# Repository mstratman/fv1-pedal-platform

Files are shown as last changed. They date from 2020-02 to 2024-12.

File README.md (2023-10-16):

# Mimir's Well

This repository contains everything you need to build the [Mimir's Well](https://mas-effects.com/mimirs-well/) guitar pedal. You can build it from a [kit or PCB](https://shop.mas-effects.com/collections/diy/mimirs-well).

Directories:

* `arduino`: code for the display driver, and for writing the "yellow" EEPROMs
* `assembly`: documents to help people building from a [kit or PCB](https://shop.mas-effects.com/collections/diy/mimirs-well)
* `eeprom-helper`: simple tool to help when creating EEPROMs. see its README 
* `pcb`: gerber and dxf files, e.g. if you want to produce your own PCB
* `schematics`: schematics
* `v1`: a one-off prototype (which is now my most-used pedal)

## Writing EEPROMs

The pedal has 2 pairs of 24LC32A EEPROMs. Each pair contains a bank of 8 programs, and has a "Yellow" EEPROM and a "Blue" EEPROM.  The colors aren't significant, and just refer to the color I use when writing each chip's number on it. It's a simple way to avoid getting them mixed up.

There are lots of ways to write to EEPROMs, and this is only one of them.

### Yellow

This holds the program name and control labels for each program in the bank. I use this [EEPROM Helper](https://github.com/mstratman/fv1-pedal-platform/tree/master/eeprom-helper) script to make the label text file, or the arduino file.

#### Using an EEPROM programmer:

You can write to it using these shell scripts: [burn-labels.sh and make-labels.sh](https://gist.github.com/mstratman/d541932adb592097963afa8c9aeca4c1).

####  Using an arduino:

You can also write it using an [Arduino sketch](/arduino/eeprom/eeprom.ino). You can hook it up as follows:

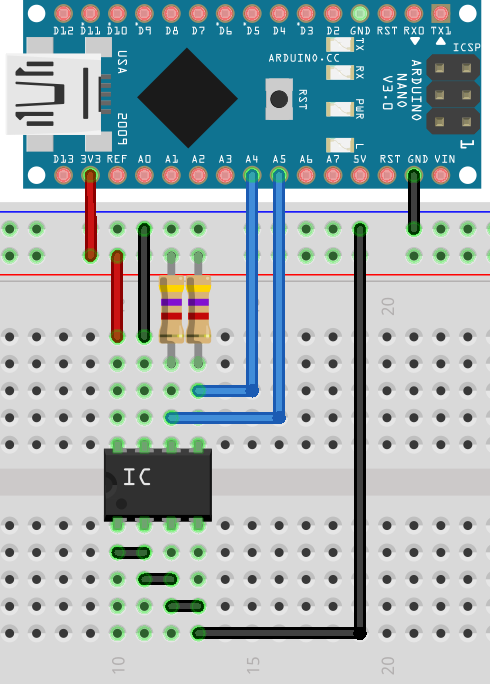
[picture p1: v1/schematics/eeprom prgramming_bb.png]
connecting EEPROM to Arduino for writing


### Blue

This holds the FV-1 programs.

You may be be able to write the banks using an arduino and a custom sketch, but I simply use a very inexpensive EEPROM programmer.  Specifically I use a USB CH341 EEPROM programmer.  These can be found for about $5.  You may need to find and install USB drivers. 

I use the [ch341eeprom](https://github.com/command-tab/ch341eeprom) commandline tool on Mac OS X to write the data to the USB programmer.  If you're not on Mac you'll need to find an alternative tool.

To create these banks I do the following:

1. Create a "hex" bank using [SpinAsm assembler](http://spinsemi.com/products.html)
    1. Unfortunately this only runs on Windows. [An alternate assembler](https://github.com/ndf-zz/asfv1) exists but I haven't tried it.
2. Convert it to a "bin" file using the `srec_cat` util from the "srecord" package
    1. `brew install srecord` on Mac
    2. `srec_cat bank-input.hex -Intel -o bank-output.bin -binary`
3. Erase the EEPROM, probably optional
    1. `ch341eeprom -v -s 24c32 -e`
4. Write the bin file
    1. `ch341eeprom -v -s 24c32 -w bank-output.bin`
5. Check for problems. Optional but recommended
    1. `ch341eeprom -v -s 24c32 -r /tmp/eeprom.bin # read back the data`
    2. `diff /tmp/eeprom.bin bank-output.bin # this should not output anything`

[Here is a script I use for steps 2-5](https://gist.github.com/mstratman/5ede44bfd3bc87219b2a90b9920d51e1).

## "EEPROM Helper" tool

To help streamline this process I have a really simple tool I use: [eeprom helper](https://github.com/mstratman/fv1-pedal-platform/tree/master/eeprom-helper)

It's just a simple javascript page that lets me check which programs I'll be burning, then it does 2 things:

1. Gives a snippet of arduino code or a text list of labels for the burning the Yellow chip, described above.
2. Lists the spn files for reference, which is helpful when manually working with SpinAsm Assembler in step 1 while burning the Blue chip.

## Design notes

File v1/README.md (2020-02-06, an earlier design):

# FV-1 Pedal Platform

## Overview

This project contains the files for a guitar effects pedal utilizing a TFT screen, Atmega display driver, FV-1 DSP module, and EEPROMs to hold the FV-1 programs and labels.

The schematics and PCBs included reflect the v1 prototype, which was pieced together utilizing an [Arachnid board from Pedalpcb](https://www.pedalpcb.com/product/arachnid/), and 4 etched PCBs for additional functionality.  Future builds will be simplified to use a single, manufactured board.

## DSP code to run on the pedal

**[https://mstratman.github.io/fv1-programs/](https://mstratman.github.io/fv1-programs/)**

## PCBs

* [Arachnid board from Pedalpcb](https://www.pedalpcb.com/product/arachnid/) is very similar to the "typical application" circuit from the FV-1 datasheet
* 5V voltage regulator board: This is not included in the `pcbs` directory of this project. It's simply a small piece of veroboard with the circuit shown in the [pedal schematic](schematics/pedal.png).
* TFT board
* Arduino and EEPROM board
* Rotary switch board

## Arduino or Atmega328p

This was originally built using an Atmega328p rather than full nano board, but the, and you could just as easily use that. I recommend setting it up with a 16MHz crystal to maximize display refresh rate.

I switched to an Arduino Nano board because it was quicker and easier to test and debug since it has a built-in USB controller, and I found a pack of clone boards for a few dollars. Now that the code is stable, this isn't nearly as important, so an Atmega328p would be fine.

## Rotary switch

We're reading the rotary switch from both the FV-1 and the Atmega. We really only need one set of diodes to do this, but wiring into the FV-1's Arachnid board is more trouble than it's worth, so we just have a duplicate set of them for the Atmega to use.

When v2 is built onto a single board, we will eliminate the duplication.

## EEPROM

We have two EEPROM's.  One for the FV-1 with the DSP code, and one for the Atmega with the names of the programs and the labels.  We could just hard-code the program names and control labels into the Atmega, but this allows us to swap out programs more easily without needing to reprogram it.

For ease of programming, and because we control the data going onto it, we're simply going to store each string on one of the 32byte pages. This allows us to ignore page boundaries, and simply read and write one page at a time.

Note: Running the EEPROM off 3.3V did not work with my Arduino board.  It works fine with 5V though.

## Bank switching

...

## Fonts

The `.h` files for the fonts are created using [fontconvert](https://github.com/adafruit/Adafruit-GFX-Library/tree/master/fontconvert) from the [Adafruit GFX library](https://github.com/adafruit/Adafruit-GFX-Library).

## What's next (v2)

If I build a v2 using a fabricated board, I'll simplify it to a single set of switching diodes.

Second, I'll let it switch between two pairs of eeproms for 16 instead of 8 custom programs.

Possibly: I'll use the arduino to control program selection and have it skip over the built-in FV-1 programs that aren't very useful for guitar

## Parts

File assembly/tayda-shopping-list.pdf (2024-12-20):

### Parts - grouped

Designa tor | Qty | Name | Tayda Part # | Link | NOTE
C4,C11 | 2 | 10u | A-1067 | https://www.taydaelectronics.com/10uf-35v-105c-jrb-radial-electrolytic-capacitor-5x11mm.html (https://www.taydaelectronics.com/10uf-35v-105c-jrb-radial-electrolytic-capacitor-5x11mm.html)
C6,C10 | 2 | 100u | A-972 | https://www.taydaelectronics.com/100uf-16v-105c-jrb-radial-electrolytic-capacitor-5x11mm.html (https://www.taydaelectronics.com/100uf-16v-105c-jrb-radial-electrolytic-capacitor-5x11mm.html)
C7,C8 | 2 | 47u | A-6062 | https://www.taydaelectronics.com/47uf-25v-105c-jrb-radial-electrolytic-capacitor-5x11mm.html (https://www.taydaelectronics.com/47uf-25v-105c-jrb-radial-electrolytic-capacitor-5x11mm.html)
C1,C9 | 2 | 100n | A-6984 | https://www.taydaelectronics.com/0-1uf-100v-5-polyester-film-box-type-capacitor-jfj.html (https://www.taydaelectronics.com/0-1uf-100v-5-polyester-film-box-type-capacitor-jfj.html)
C2,C12, C13,C15 ,C16,C1 9 | 6 | 1u MLCC | A-5706 | https://www.taydaelectronics.com/1-uf-50v-multilayer-monolithic-ceramic-capacitor-x7r-jym-5705.html (https://www.taydaelectronics.com/1-uf-50v-multilayer-monolithic-ceramic-capacitor-x7r-jym-5705.html)
C3 | 1 | 1n | A-557 | https://www.taydaelectronics.com/1nf-0-001uf-100v-5-polyester-film-box-type-capacitor.html (https://www.taydaelectronics.com/1nf-0-001uf-100v-5-polyester-film-box-type-capacitor.html)
C5 | 1 | 15p | A-1393 | https://www.taydaelectronics.com/15pf-50v-multilayer-monolithic-ceramic-capacitor.html (https://www.taydaelectronics.com/15pf-50v-multilayer-monolithic-ceramic-capacitor.html)
C14 | 1 | 2n2 | A-4413 | https://www.taydaelectronics.com/2-2nf-0-0022uf-100v-5-polyester-film-box-type-capacitor-jfj.html (https://www.taydaelectronics.com/2-2nf-0-0022uf-100v-5-polyester-film-box-type-capacitor-jfj.html)
C17 | 1 | 220p | A-7056 | https://www.taydaelectronics.com/220-pf-50v-multilayer-monolithic-ceramic-capacitor-c0g.html (https://www.taydaelectronics.com/220-pf-50v-multilayer-monolithic-ceramic-capacitor-c0g.html)
C18 | 1 | 470p | A-5704 | https://www.taydaelectronics.com/470pf-50v-multilayer-monolithic-ceramic-capacitor-x7r-jym.html (https://www.taydaelectronics.com/470pf-50v-multilayer-monolithic-ceramic-capacitor-x7r-jym.html)
R1,R3 | 2 | 1M | A-2277 | https://www.taydaelectronics.com/resistors/1-4w-metal-film-resistors/10-x-resistor-1m-ohm-1-4w-1-metal-film-pkg-of-10.html (https://www.taydaelectronics.com/resistors/1-4w-metal-film-resistors/10-x-resistor-1m-ohm-1-4w-1-metal-film-pkg-of-10.html)
R2,R4,R 25,R29,R 27,R26,R 24,R23,R 22,R21 | 10 | 1k | A-2200 | https://www.taydaelectronics.com/resistors/1-4w-metal-film-resistors/10-x-resistor-1k-ohm-1-4w-1-metal-film-pkg-of-10.html (https://www.taydaelectronics.com/resistors/1-4w-metal-film-resistors/10-x-resistor-1k-ohm-1-4w-1-metal-film-pkg-of-10.html)
R5,R6,R 7,R8,R9, R39 | 6 | 10k | A-2203 | https://www.taydaelectronics.com/resistors/1-4w-metal-film-resistors/10-x-resistor-10k-ohm-1-4w-1-metal-film-pkg-of-10.html (https://www.taydaelectronics.com/resistors/1-4w-metal-film-resistors/10-x-resistor-10k-ohm-1-4w-1-metal-film-pkg-of-10.html)
R28,R37 | 2 | 100 | A-2245 | https://www.taydaelectronics.com/resistors/1-4w-metal-film-resistors/resistor-100-ohm-1-4w-1-metal-film-pkg-of-10.html (https://www.taydaelectronics.com/resistors/1-4w-metal-film-resistors/resistor-100-ohm-1-4w-1-metal-film-pkg-of-10.html)
R30,R38, R10,R11, R12 | 5 | 100k | A-2248 | https://www.taydaelectronics.com/resistors/1-4w-metal-film-resistors/10-x-resistor-100k-ohm-1-4w-1-metal-film-pkg-of-10.html (https://www.taydaelectronics.com/resistors/1-4w-metal-film-resistors/10-x-resistor-100k-ohm-1-4w-1-metal-film-pkg-of-10.html)
R31,R32, R33,R34, R35,R36 | 6 | 15k | A-2182 | https://www.taydaelectronics.com/resistors/1-4w-metal-film-resistors/10-x-resistor-15k-ohm-1-4w-1-metal-film-pkg-of-10.html (https://www.taydaelectronics.com/resistors/1-4w-metal-film-resistors/10-x-resistor-15k-ohm-1-4w-1-metal-film-pkg-of-10.html)
R20 | 1 | 220 | A-2246 | https://www.taydaelectronics.com/resistors/1-4w-metal-film-resistors/resistor-220-ohm-1-4w-1-metal-film-pkg-of-10.html (https://www.taydaelectronics.com/resistors/1-4w-metal-film-resistors/resistor-220-ohm-1-4w-1-metal-film-pkg-of-10.html)
R19,R18, R17,R16 | 4 | 2k | A-2307 | https://www.taydaelectronics.com/resistors/1-4w-metal-film-resistors/resistor-2k-ohm-1-4w-1-metal-film-pkg-of-10.html (https://www.taydaelectronics.com/resistors/1-4w-metal-film-resistors/resistor-2k-ohm-1-4w-1-metal-film-pkg-of-10.html)
R13,R14, R15 | 3 | 4.7k | A-2310 | https://www.taydaelectronics.com/resistors/1-4w-metal-film-resistors/10-x-resistor-4-7k-ohm-1-4w-1-metal-film-pkg-of-10.html (https://www.taydaelectronics.com/resistors/1-4w-metal-film-resistors/10-x-resistor-4-7k-ohm-1-4w-1-metal-film-pkg-of-10.html)
POT1,P OT2,POT 3,VOLU ME | 4 | B100K | A-2963 | https://www.taydaelectronics.com/b100k-ohm-linear-taper-potentiometer-round-shaft-pc-mount-l.html (https://www.taydaelectronics.com/b100k-ohm-linear-taper-potentiometer-round-shaft-pc-mount-l.html)
MIX | 1 | B10K | A-2969 | https://www.taydaelectronics.com/b10k-ohm-linear-taper-potentiometer-round-shaft-pc-mount-l.html (https://www.taydaelectronics.com/b10k-ohm-linear-taper-potentiometer-round-shaft-pc-mount-l.html)
Q1 | 1 | 2N3904 | A-111 | https://www.taydaelectronics.com/2n3904-npn-general-propose-transistor.html (https://www.taydaelectronics.com/2n3904-npn-general-propose-transistor.html)

1

Q2 | 1 | BS170 | A-096 | https://www.taydaelectronics.com/bs170-mosfet-n-channel-60v-0-5a.html
DT-38 | 1 | 32.768 3x8MM | A-1592 | https://www.taydaelectronics.com/32-768-khz-crystal-cylender-3-x-8-mm.html (https://www.taydaelectronics.com/32-768-khz-crystal-cylender-3-x-8-mm.html) | INCLUDED IN KIT
D10,D2, D3,D4,D 6,D5,D7, D8,D9 | 9 | 1N4148 | A-157 | https://www.taydaelectronics.com/1n4148-switching-signal-diode.html
D1 | 1 | 1N5817 | A-159 | https://www.taydaelectronics.com/1n5817-diode-schottky-1a-20v.html
SW1 | 1 | SP8T rotary switch | | | INCLUDED IN KIT
SW2 | 1 | 3PDT On-Off-On | A-5488 | https://www.taydaelectronics.com/mini-toggle-switch-1m-series-3pdt-on-off-on.html (https://www.taydaelectronics.com/mini-toggle-switch-1m-series-3pdt-on-off-on.html)
U1 | 1 | FV-1 | | | INCLUDED IN KIT
U2 | 1 | TL074 | A-1138 | https://www.taydaelectronics.com/tl074-quad-operational-amplifier-j-fet-pdip-14-tl074cn.html (https://www.taydaelectronics.com/tl074-quad-operational-amplifier-j-fet-pdip-14-tl074cn.html)
U5 | 1 | L78L33 | A-492 | https://www.taydaelectronics.com/l78l33acz-78l33-3-3v-voltage-regulator-ic.html (https://www.taydaelectronics.com/l78l33acz-78l33-3-3v-voltage-regulator-ic.html)
U7 | 1 | 7805 | A-179 | https://www.taydaelectronics.com/lm7805-l7805-7805-voltage-regulator-ic-5v-1-5a.html (https://www.taydaelectronics.com/lm7805-l7805-7805-voltage-regulator-ic-5v-1-5a.html)
U3, U4, U9, U11 | 4 | 24LC32 A (MUST BE PROGR AMME D) | | | INCLUDED IN KIT
U8 (silkscree n shows U6) | 1 | ILI9341-2.8 TFT (SPI) | | | INCLUDED IN KIT
U10 | 1 | Arduino Nano (MUST BE PROGR AMME D) | | | INCLUDED IN KIT

(plus all off-board hardware )

2

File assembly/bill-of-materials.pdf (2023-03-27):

### Parts - grouped

Designator | Qty | Name
C4,C11 | 2 | 10u
C6,C10 | 2 | 100u
C7,C8 | 2 | 47u
C1,C9 | 2 | 100n
C2,C12,C13,C15,C16,C19 | 6 | 1u MLCC
C3 | 1 | 1n
C5 | 1 | 15p
C14 | 1 | 2n2
C17 | 1 | 220p
C18 | 1 | 470p
R1,R3 | 2 | 1M
R2,R4,R25,R29,R27,R26,R24,R23,R22,R21 | 10 | 1k
R5,R6,R7,R8,R9,R39 | 6 | 10k
R28,R37 | 2 | 100
R30,R38,R10,R11,R12 | 5 | 100k
R31,R32,R33,R34,R35,R36 | 6 | 15k
R20 | 1 | 220
R19,R18,R17,R16 | 4 | 2k
R13,R14,R15 | 3 | 4.7k
POT1,POT2,POT3,VOLUME | 4 | B100K | R20 | 220
MIX | 1 | B10K | R21 | 1k
Q1 | 1 | 2N3904 | R22 | 1k
Q2 | 1 | BS170 | R23 | 1k
DT-38 | 1 | 32.768 3x8MM | R24 | 1k
D10,D2,D3,D4,D6,D5,D7,D8,D9 | 9 | 1N4148 | R25 | 1k
D1 | 1 | 1N5817 | R26 | 1k
SW1 | 1 | SP8T rotary switch | R27 | 1k
SW2 | 1 | 3PDT On-Off-On | R28 | 100
U1 | 1 | FV-1 | R29 | 1k
U2 | 1 | TL074 | R30 | 100k
U5 | 1 | L78L33 | R31 | 15k
U7 | 1 | 7805 | R32 | 15k
U3, U4, U9, U11 | 4 | 24LC32A (MUST BE PROGRAMMED) | R33 | 15k
| | | R34 | 15k
| | | R35 | 15k
| | | R36 | 15k
| | | R37 | 100
| | | R38 | 100k
| | | R39 | 10k
U8 (silkscreen shows U6) | 1 | ILI9341-2.8 TFT (SPI)
U10 | 1 | Arduino Nano (MUST BE PROGRAMMED)

(plus all off-board hardware)

### Caps - ordered

Designator | Name | code
C1 | 100n | 104
C2 | 1u MLCC
C3 | 1n | 102
C4 | 10u
C5 | 15p | 150
C6 | 100u
C7 | 47u
C8 | 47u
C9 | 100n | 104
C10 | 100u
C11 | 10u
C12 | 1u MLCC
C13 | 1u MLCC
C14 | 2n2 | 222
C15 | 1u MLCC
C16 | 1u MLCC
C17 | 220p | 221
C18 | 470p | 471
C19 | 1u MLCC

### Resistors - ordered

Designator | Name
R1 | 1M
R2 | 1k
R3 | 1M
R4 | 1k
R5 | 10k
R6 | 10k
R7 | 10k
R8 | 10k
R9 | 10k
R10 | 100k
R11 | 100k
R12 | 100k
R13 | 4.7k
R14 | 4.7k
R15 | 4.7k
R16 | 2k
R17 | 2k
R18 | 2k
R19 | 2k

1

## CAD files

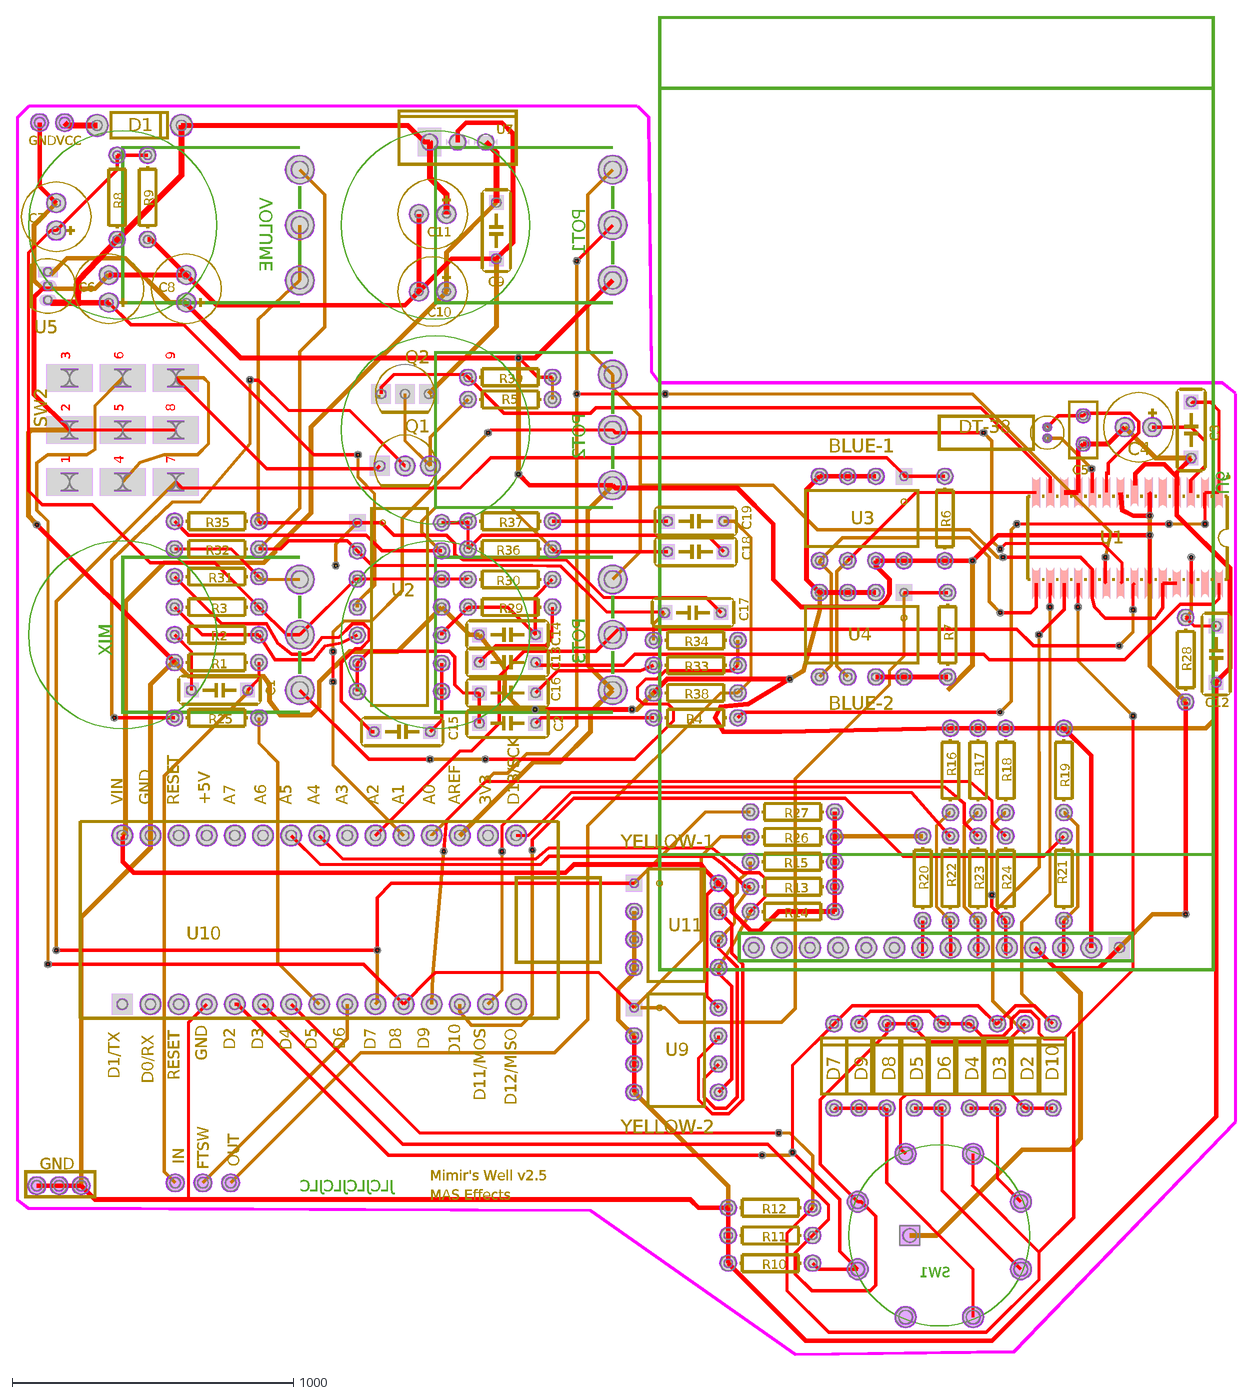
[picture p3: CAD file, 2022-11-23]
pcb/mimirs-well-2.5.dxf
JLCJLCJLCJLC
SW1
FTSW
GND
OUT
IN
VCC
Mimir's Well v2.5
MAS Effects
YELLOW-1
YELLOW-2
BLUE-1
BLUE-2
U6
POT1
POT2
POT3
VOLUME
MIX
C4
C6
C7
C8
C10
C11
D1
U11
U9
U10
D1/TX
+5V
D12/MISO
VIN
D13/SCK
D0/RX
RESET
D2
D3
D4
D5
D6
D7
D8
D9
D10
D11/MOSI
3V3
AREF
A0
A1
A2
A3
A4
A5
A6
A7
R27
R26
R24
R23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

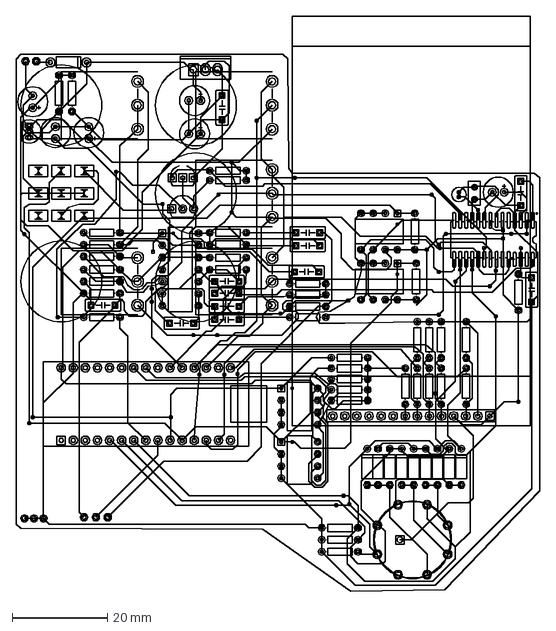
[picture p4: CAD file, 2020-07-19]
pcb/mimirs-well-2.4.dxf
110.0 x 120.7 mm

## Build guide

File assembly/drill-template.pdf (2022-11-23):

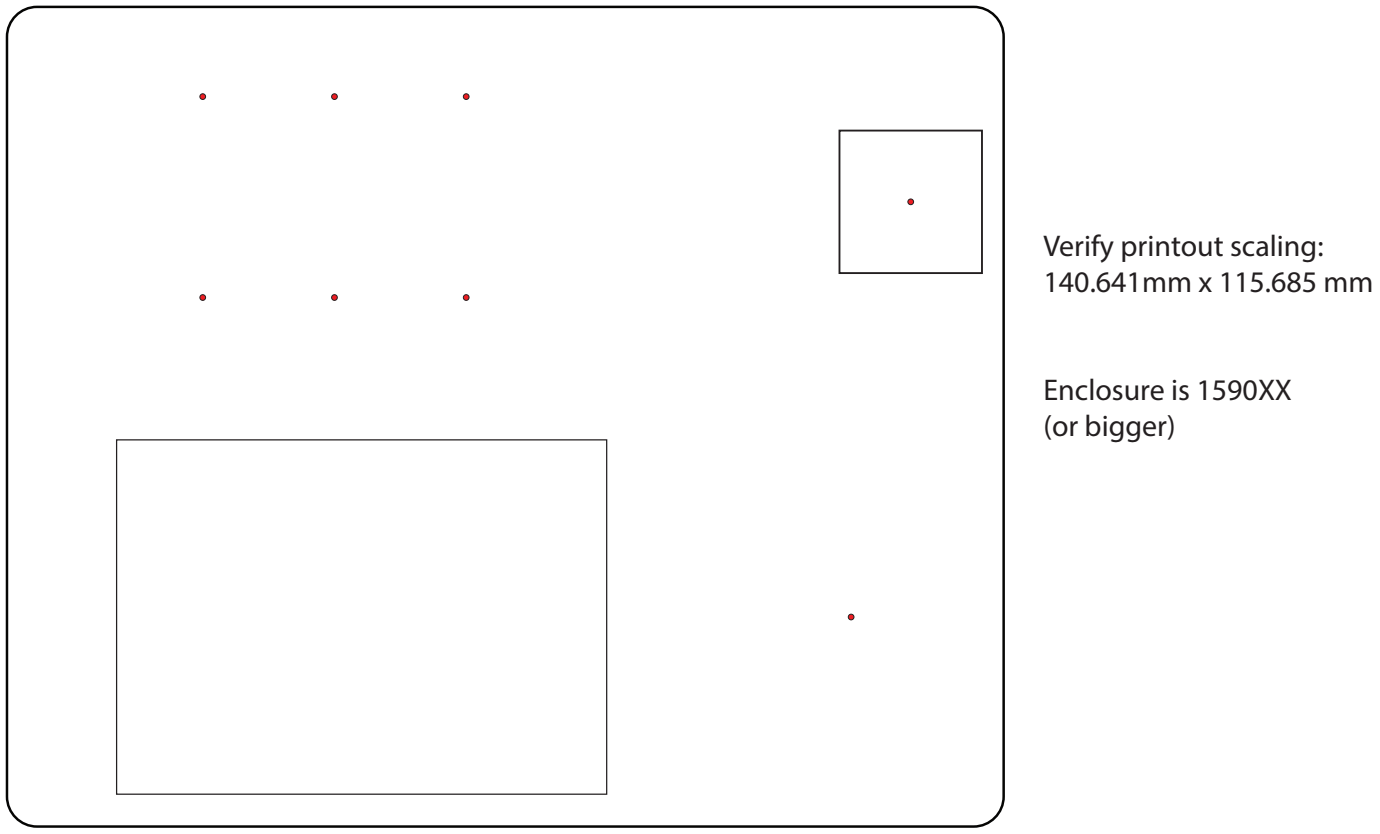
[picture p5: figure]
Verify printout scaling: 140.641mm x 115.685 mm; Enclosure is 1590XX (or bigger)
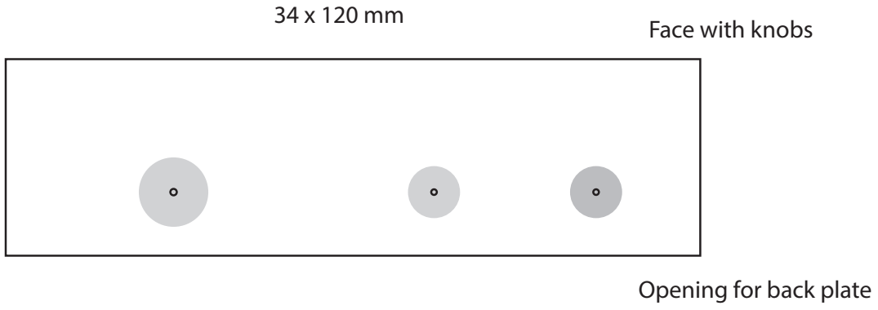
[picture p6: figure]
Opening for back plate; Face with knobs

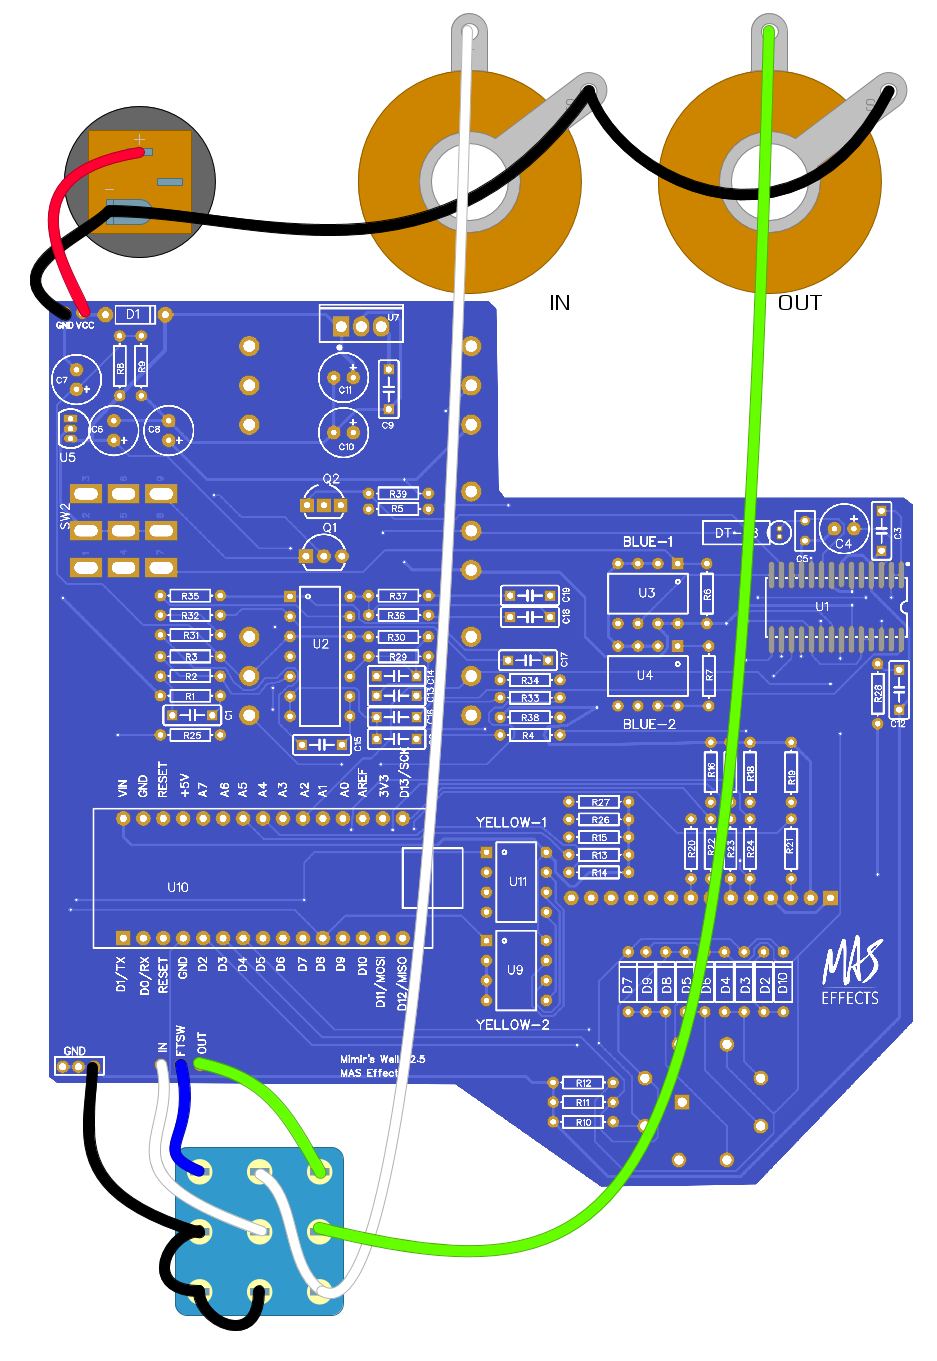
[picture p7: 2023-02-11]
assembly/mimirs-well-wiring.png

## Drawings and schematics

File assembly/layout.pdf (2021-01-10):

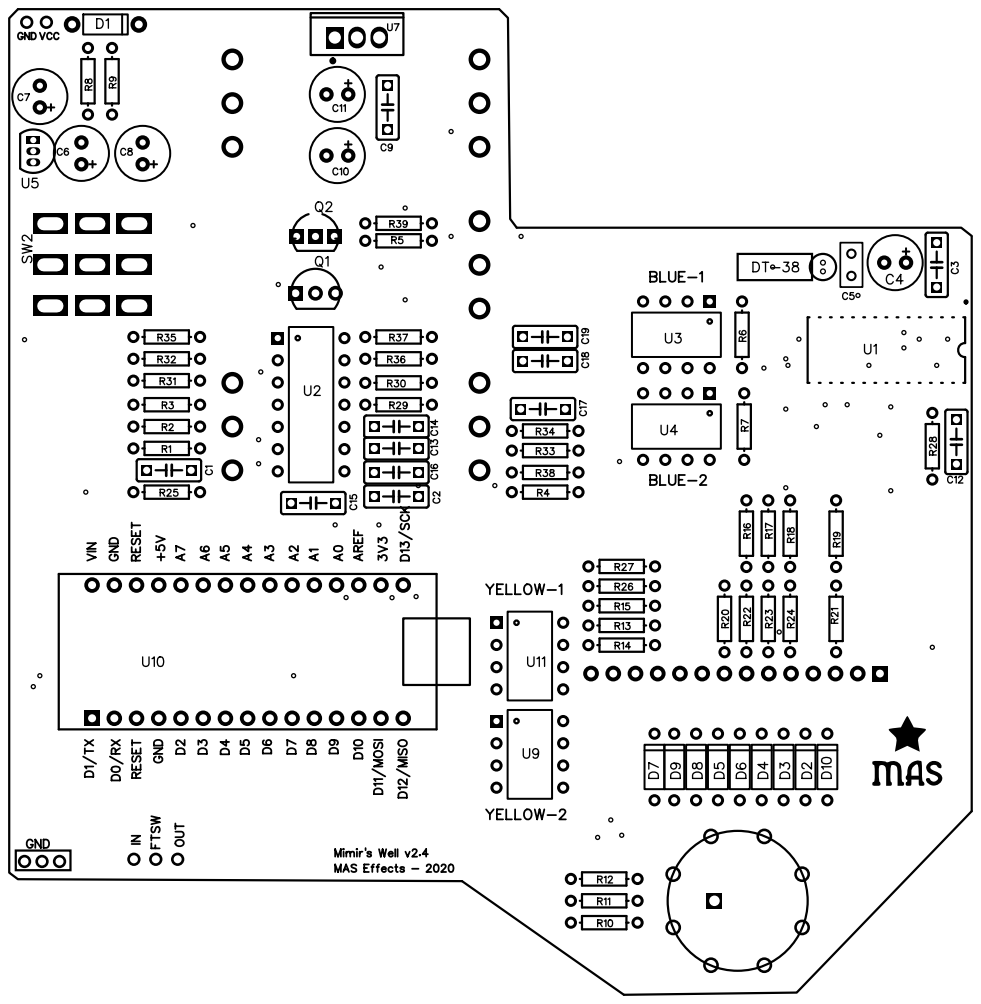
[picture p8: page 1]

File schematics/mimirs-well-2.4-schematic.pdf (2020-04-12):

### VREF

### VREF

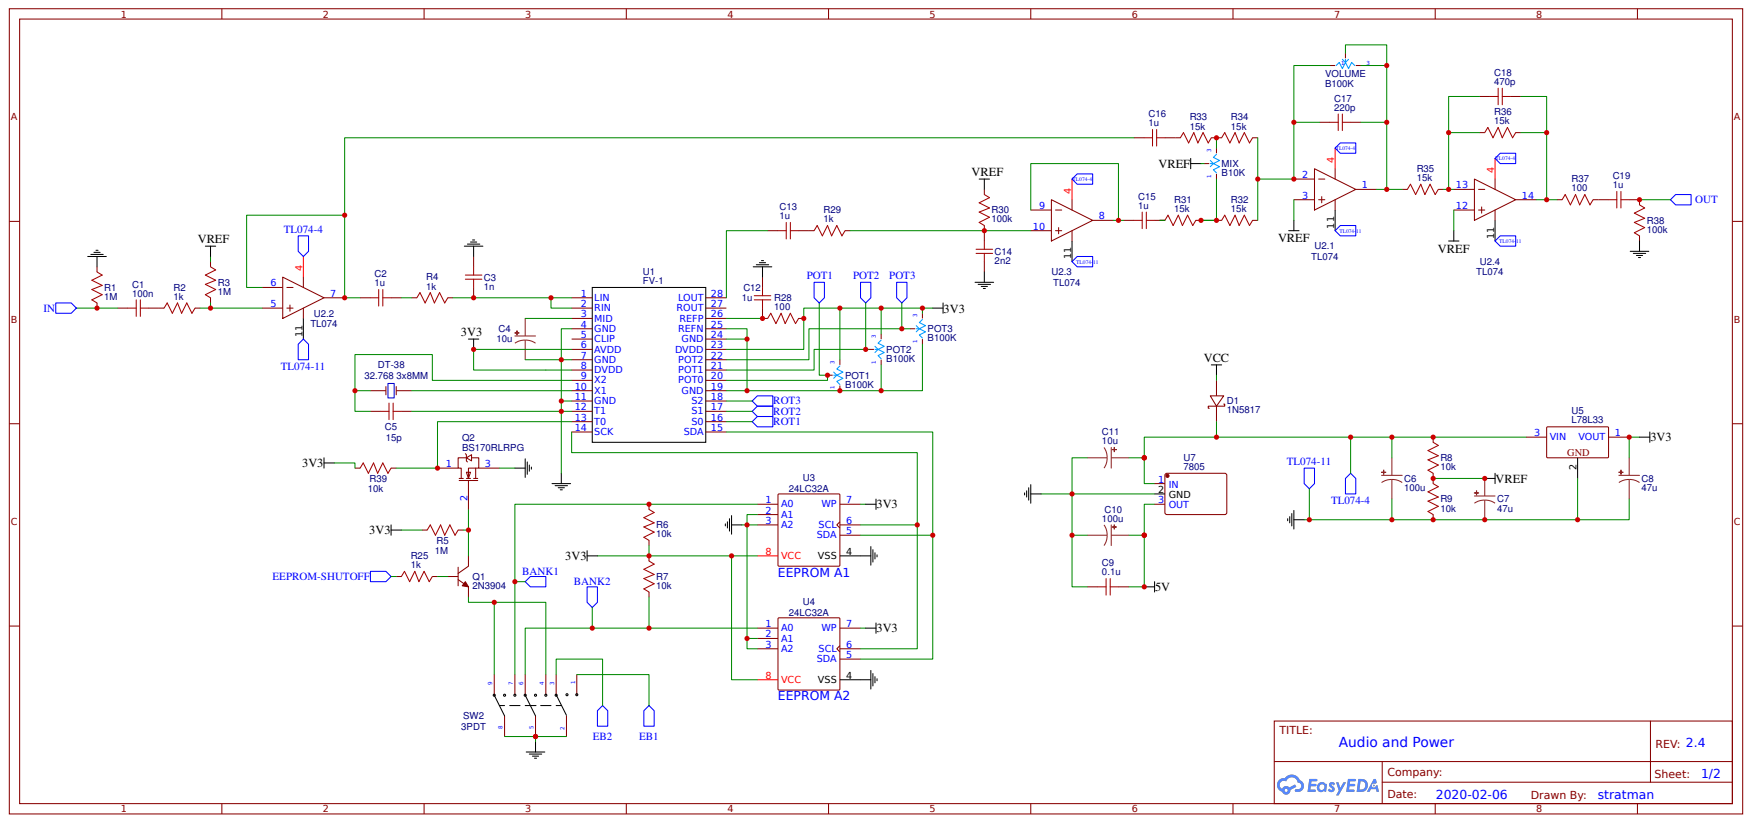
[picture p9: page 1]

3V3

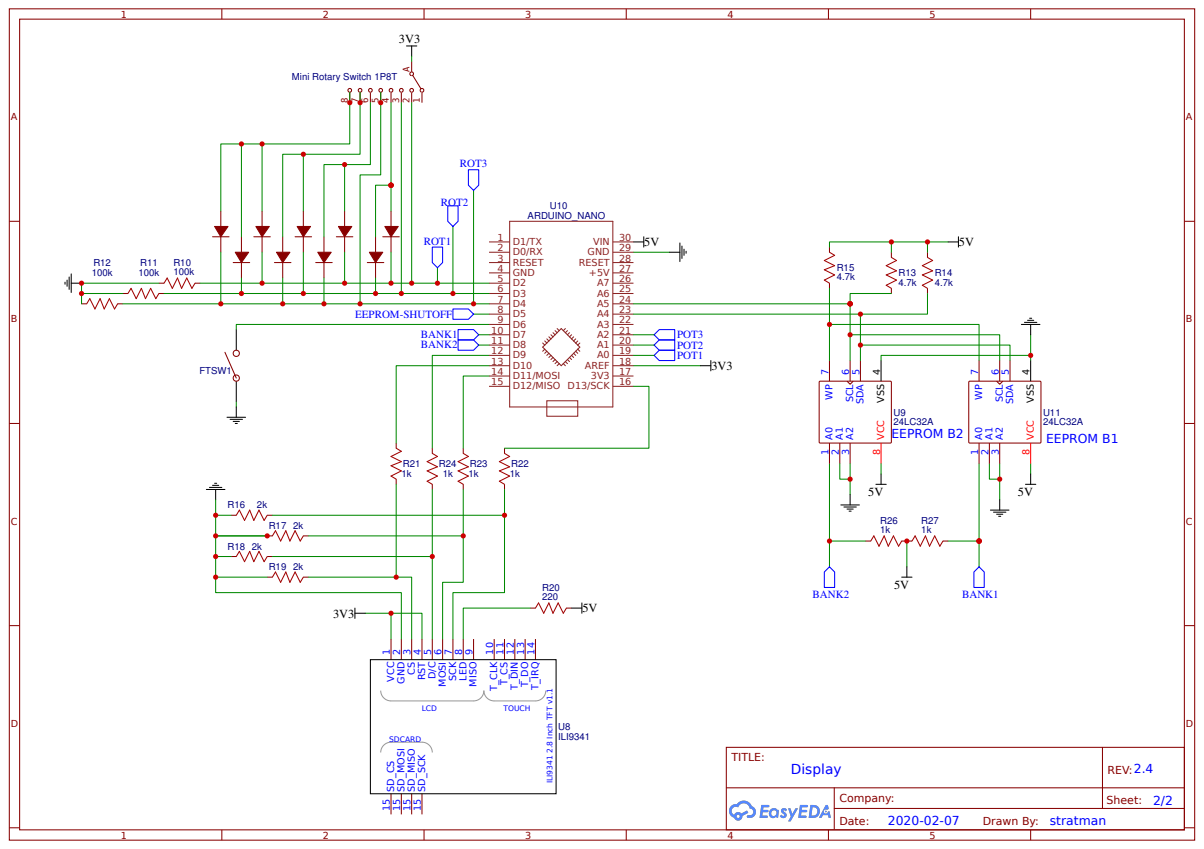
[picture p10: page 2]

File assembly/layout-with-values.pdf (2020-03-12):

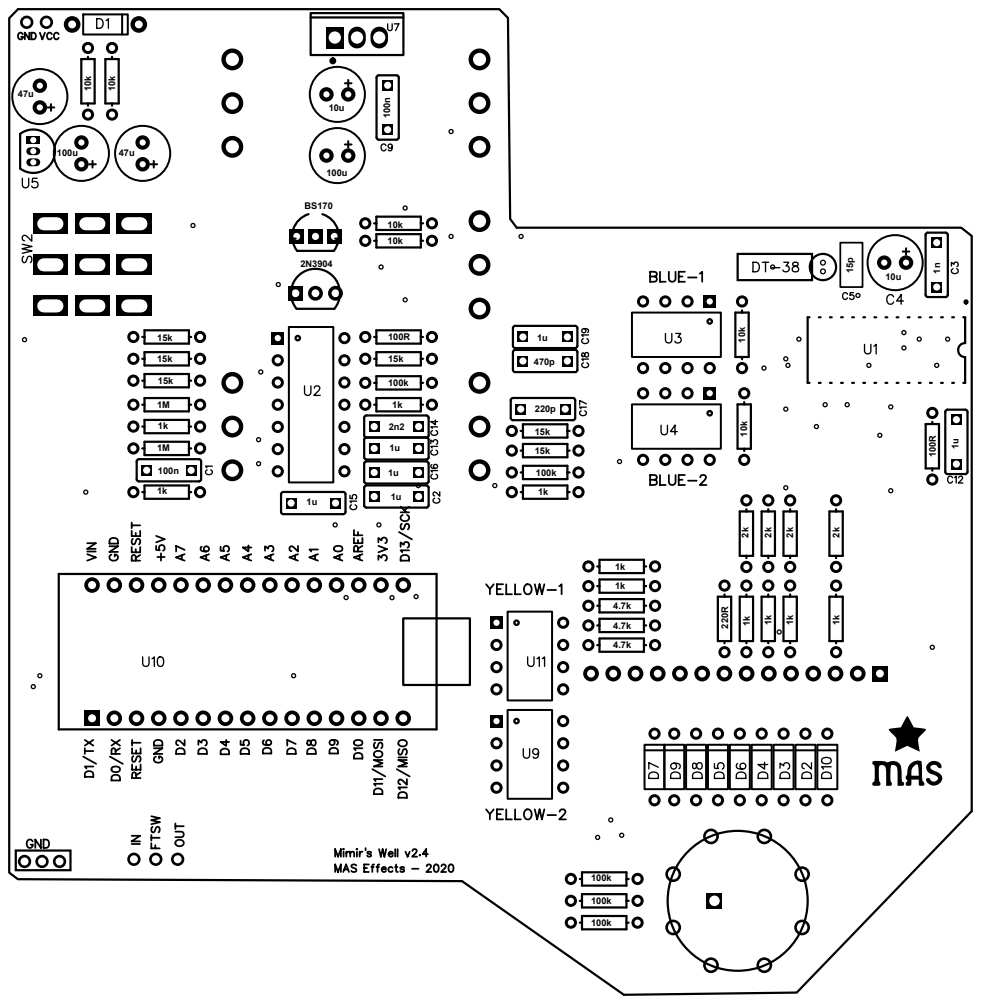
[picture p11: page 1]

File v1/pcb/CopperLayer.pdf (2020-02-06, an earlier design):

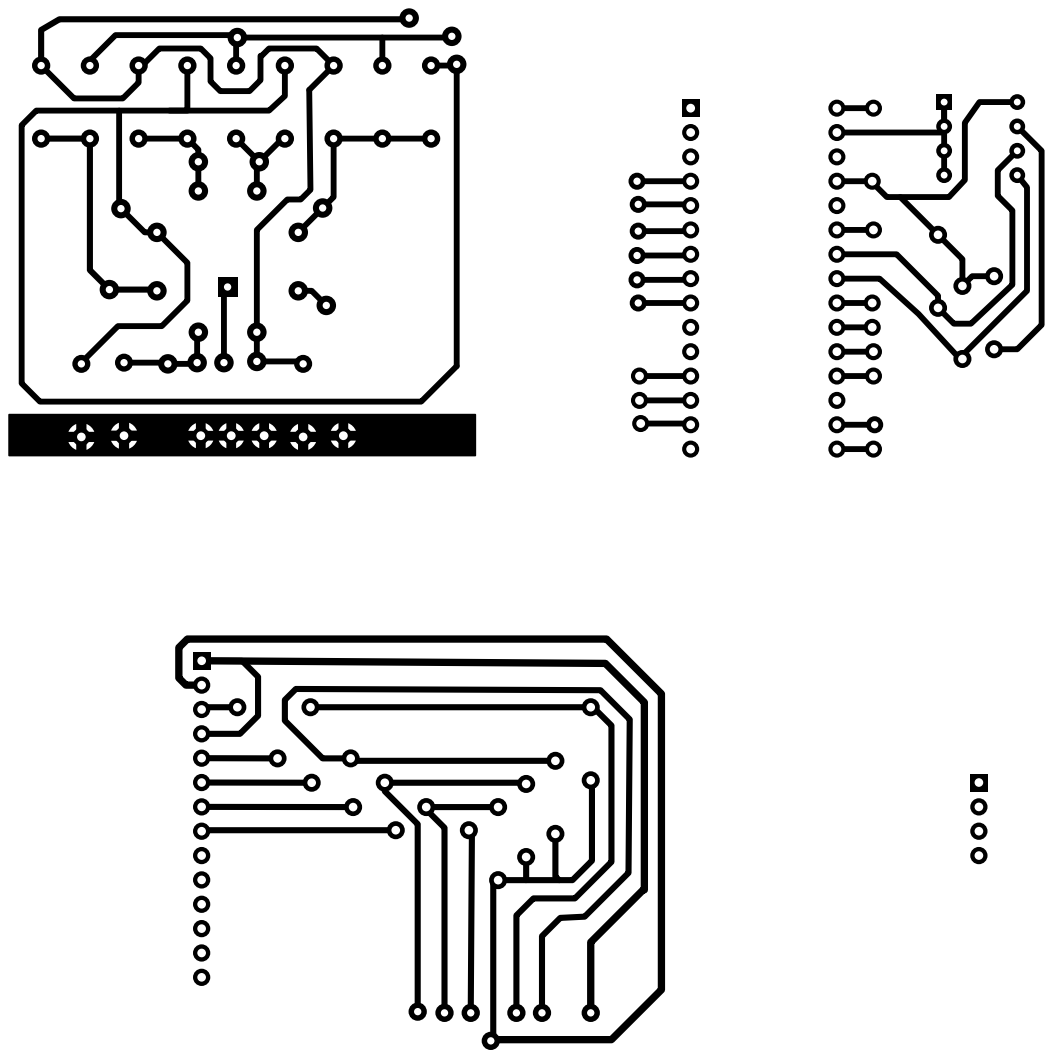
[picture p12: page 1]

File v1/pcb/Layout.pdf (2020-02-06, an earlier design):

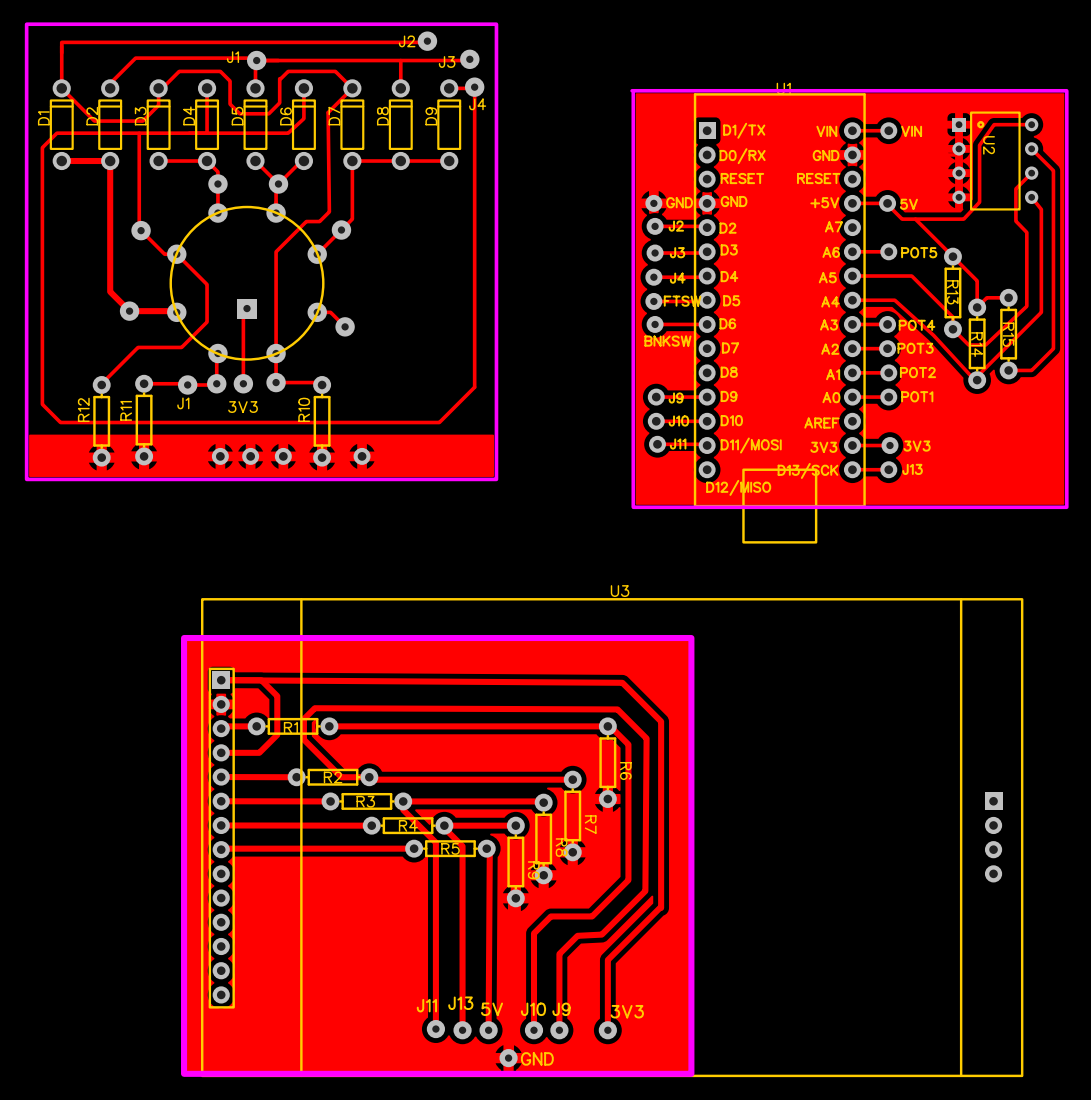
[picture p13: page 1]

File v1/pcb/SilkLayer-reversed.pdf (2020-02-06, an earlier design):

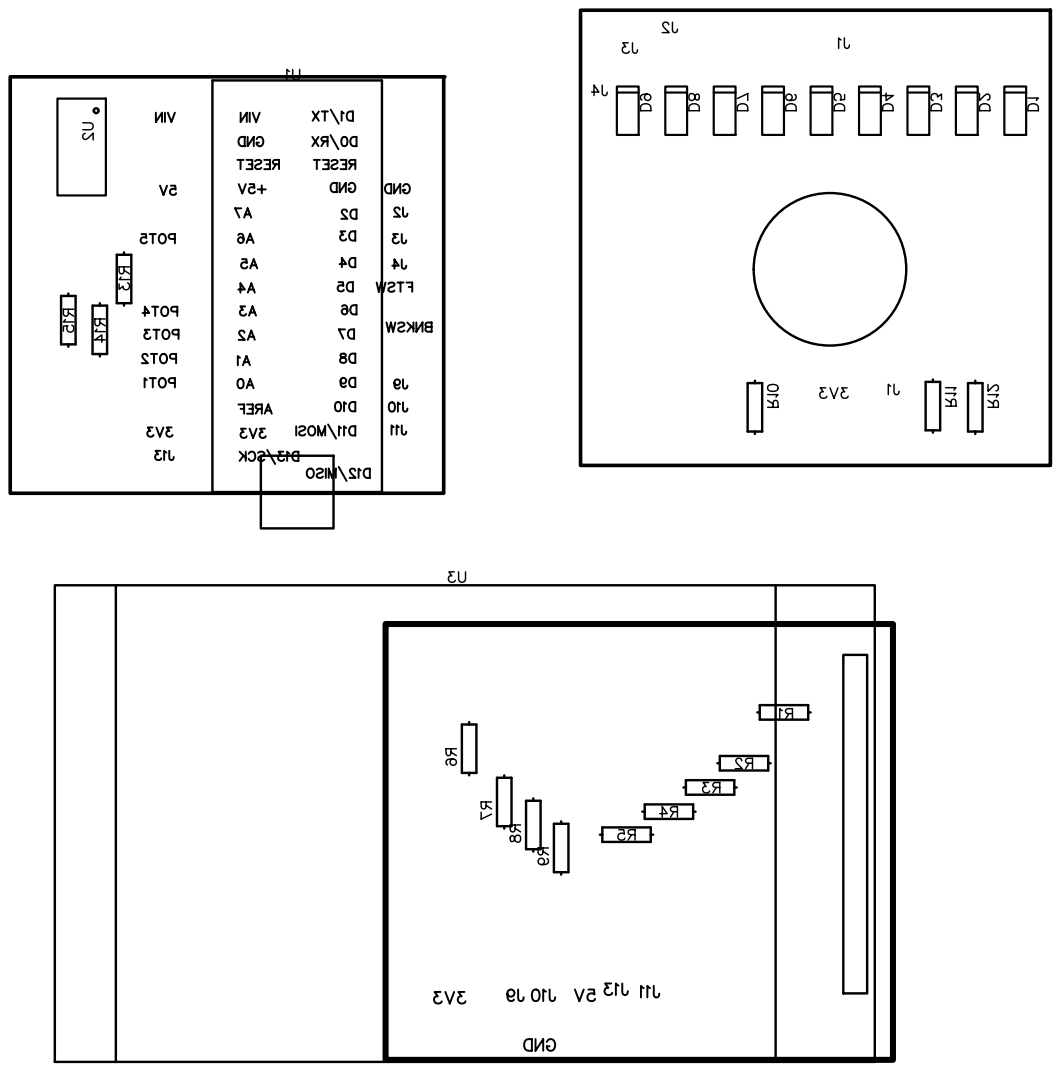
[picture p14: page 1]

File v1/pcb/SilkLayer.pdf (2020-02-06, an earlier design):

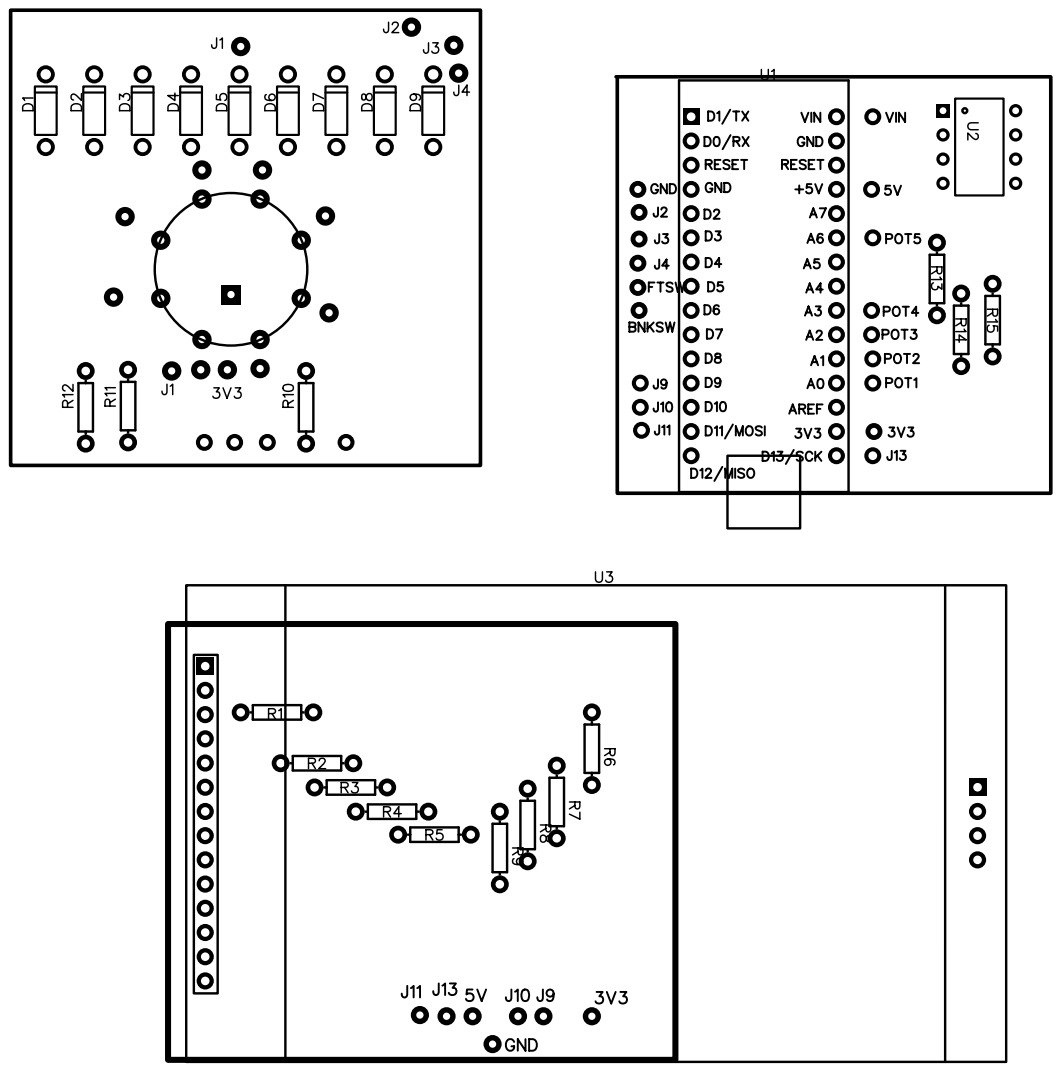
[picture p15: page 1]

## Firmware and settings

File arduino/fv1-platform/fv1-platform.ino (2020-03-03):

#include <Wire.h>
#include "SPI.h"
#include "Adafruit_GFX.h"
#include "Adafruit_ILI9341.h"
#include "Optima9pt7b.h"
#include "euphorigenic14pt7b.h"

#define PIN_TFT_DC 9
#define PIN_TFT_CS 10

#define PIN_BYPASS 6

#define PIN_BANK1 8
#define PIN_BANK2 7
#define PIN_EEPROM_SHUTOFF 5

#define DEBOUNCE_TIME 150

#define PIN_ROT1 2 // 1p8t rotary switch
#define PIN_ROT2 3
#define PIN_ROT3 4

/* We're using a 24LC32A */
#define EEPROM_ADDRESS B1010000 // 1010 + 3 bits (000) for pins 1,2,3
#define EEPROM_BUFFER_SIZE 30 // It has a 32 byte page write buffer, but make this as small as possible 
#define EEPROM_PAGE_SIZE 32
#define EEPROM_CLOCK_SPEED 400000

#define TFT_WIDTH 240
#define TFT_HEIGHT 320
#define BAR_Y_START 5
#define BAR_SMOOTHING 5 // If pot changes by this much or less, don't change the bar width. Prevents stuttering.
#define BAR_WIDTH 234 // not including margins
#define BAR_HEIGHT 28 // not including margins
#define BAR_MARGIN 3
#define BAR_SECTION_TOTAL_HEIGHT 65 // bar + margins*2 + text_height + spacing. This effectively controls bottom margin of section
#define BAR_TEXT_BASELINE_OFFSET 20 // this effectively controls margin below text
#define BAR_TEXT_MAX_HEIGHT 30 // this was found through trial and error

#define PROGRAM_LABEL_1L_OFFSET 55 // trial and error, how far down to move the label text
#define PROGRAM_LABEL_2L_OFFSET 35 // trial and error
#define PROGRAM_LABEL_2L_SPACING 35 // trial and error, space between first and second line
#define PROGRAM_BG_BUFFER 20  // Space between bottom bar and top of program name section


//#define POTS_REVERSED // Comment this out if your p1-p3 aren't reversed
#if defined(POTS_REVERSED)
const int pot_pins[] = {A2, A1, A0}; // p3, p2, p1
#define POT_LABEL_I(i) 2-i
#else
const int pot_pins[] = {A0, A1, A2}; // p1, p2, p3
#define POT_LABEL_I(i) i
#endif


// https://ee-programming-notepad.blogspot.com/2016/10/16-bit-color-generator-picker.html
const int bar_colors[3][2] = {
  {0xEC2E, 0xE73D}, //0x2127
  {0x324B, 0xE73D}, // 0xE104
  {0x65B5, 0xE73D},   // 0xFDC3
};
#define PROGRAM_BG_COLOR 0x2A2C
#define PROGRAM_LABEL_COLOR 0xFFFF
#define LABEL_COLOR 0xFFFF
#define BAR_OUTLINE_COLOR 0xFFFF
#define BG_COLOR 0x0000


Adafruit_ILI9341 tft = Adafruit_ILI9341(PIN_TFT_CS, PIN_TFT_DC);


/* The eeprom stores labels, 1 per page. They're ordered as sets of 4 strings: the program name, then 3 control labels.
   The first 8 sets are for the FV-1's internal program, the next 8 are the custom ones on the other "sister" EEPROM.
   We're going to read the needed labels on-the-fly when the program or bank changes. Initially it was loaded up once
   at boot, but it requires too much memory.
*/
char labels[5][EEPROM_BUFFER_SIZE] = {
  // 0: Program label
  "-",
  " ",
  // 1-3: control labels
  "N/A",
  "N/A",
  "N/A"
};

boolean bypassed = false;

#define BANK_INTERNAL B11
#define BANK_1 B01
#define BANK_2 B10
#define BANK_ERROR B00

byte selected_bank = BANK_ERROR;
byte selected_program = B0; // 0 to 7

byte last_program = B11111111;
byte last_bank = B11111111;
unsigned long last_program_debounce_time = 0;

void drawBars(boolean force = false);

void setup() {
  Serial.begin(9600);

  Wire.begin();
  Wire.setClock(EEPROM_CLOCK_SPEED);

  analogReference(EXTERNAL);

  for (int i = 0; i < 3; i++) {
    pinMode(pot_pins[i], INPUT);
  }

  pinMode(PIN_EEPROM_SHUTOFF, OUTPUT);
  digitalWrite(PIN_EEPROM_SHUTOFF, HIGH);

  pinMode(PIN_BYPASS, INPUT_PULLUP);
  bypassed = digitalRead(PIN_BYPASS) == HIGH;

  pinMode(PIN_BANK1, INPUT);
  pinMode(PIN_BANK2, INPUT);
  pinMode(PIN_ROT1, INPUT);
  pinMode(PIN_ROT2, INPUT);
  pinMode(PIN_ROT3, INPUT);

  tft.begin();
  tft.setRotation(0);
  tft.setTextWrap(false);


  byte bank = readBank();
  byte program = readProgram();
  last_program = program;
  last_bank = bank;
  selectProgram(bank, program, false);

  setupScreen();
}

void loop() {
  checkBypassed();
  if (! bypassed) {
    checkProgram();
    drawBars();
  }
}

byte readBank() {
  byte bank1 = (byte)(digitalRead(PIN_BANK1) == LOW ? BANK_1 : B0);
  byte bank2 = (byte)(digitalRead(PIN_BANK2) == LOW ? BANK_2 : B0);
  return (byte)(bank1 | bank2);
}
byte readProgram() {
  // Program is 0-7 depending on the combination of these 3 inputs.
  byte rot1 = digitalRead(PIN_ROT1) == LOW ? B0 : B001;
  byte rot2 = digitalRead(PIN_ROT2) == LOW ? B0 : B010;
  byte rot3 = digitalRead(PIN_ROT3) == LOW ? B0 : B100;

  return (byte)(rot1 | rot2 | rot3);
}

/* Call every loop. Changes bypassed state. */
void checkBypassed() {
  // TBD: Does this need to be debounced?
  boolean nowBypassed = digitalRead(PIN_BYPASS) == HIGH;
  if (nowBypassed != bypassed) {
    bypassed = nowBypassed;
    setupScreen();
  }
}


/* Call every loop */
void checkProgram() {
  byte bank = readBank();
  byte program = readProgram();

  if (bank != last_bank || program != last_program) {
    last_program_debounce_time = millis();
  }

  if ((selected_bank != bank || selected_program != program) && (millis() - last_program_debounce_time) > DEBOUNCE_TIME) {
    if (selected_bank != bank) {
      //Serial.println("Switching to internal ROM");
      // Temporarily swap the FV-1 over to its internal ROM so it reads the program from the newly selected bank
      digitalWrite(PIN_EEPROM_SHUTOFF, LOW);
      delay(20);
      digitalWrite(PIN_EEPROM_SHUTOFF, HIGH);
      delay(5);
      //Serial.println("Switched back to external");
    }

    Serial.print("program="); Serial.println(program); Serial.print("bank="); Serial.println(bank);
    selectProgram(bank, program, true);
  }

  last_program = program;
  last_bank = bank;
}
void selectProgram(byte bank, byte program, boolean draw) {
  //Serial.print("Bank="); Serial.println(bank);
  //Serial.print("Program="); Serial.println(program);
  selected_bank = bank;
  selected_program = program;

  _setLabelsForSelectedProgram();
  if (draw) {
    drawLabels();
  }
}

/* Call this to redraw everything. Very slow. NOT in a loop */
void setupScreen() {
  tft.fillScreen(BG_COLOR);
  if (bypassed) {
    _drawBypassed();
  } else {
    _drawBarOutlines();
    drawLabels();
    drawBars(true);
  }
}
void _drawBypassed() {
  tft.fillScreen(BG_COLOR);
  tft.setFont(&euphorigenic14pt7b);
  tft.setCursor(centerXForText("BYPASSED"), 120);
  tft.println("BYPASSED");
  // TODO: Do a nice graphic or animation?
}

/* Call this when labels change. */
void drawLabels() {
  tft.setFont(&Optima9pt7b);
  tft.setTextColor(LABEL_COLOR, BG_COLOR);
  for (int i = 0; i < 3; i++) {
    // first blank out the old text
    int y = BAR_Y_START + i * BAR_SECTION_TOTAL_HEIGHT;
    tft.fillRect(0, y, TFT_WIDTH, BAR_TEXT_MAX_HEIGHT, BG_COLOR);

    tft.setCursor(2, y + BAR_TEXT_BASELINE_OFFSET);
    // +2 to offset the program name
    tft.print(labels[POT_LABEL_I(i + 2)]);
  }

  // Fill in the bottom of the screen
  int y = BAR_Y_START + 3 * BAR_SECTION_TOTAL_HEIGHT + PROGRAM_BG_BUFFER;
  tft.fillRect(0, y, TFT_WIDTH, TFT_HEIGHT - y, PROGRAM_BG_COLOR);

  // Write the program name, centered.

  tft.setFont(&euphorigenic14pt7b);
  tft.setTextColor(PROGRAM_LABEL_COLOR, PROGRAM_BG_COLOR);

  tft.setTextWrap(true);

  boolean has_2_lines = (strlen(labels[1]) > 0);

  y += (has_2_lines ? PROGRAM_LABEL_2L_OFFSET : PROGRAM_LABEL_1L_OFFSET);

  // Line 1
  tft.setCursor(centerXForText(labels[0]), y);
  tft.print(labels[0]);

  // Line 2
  if (has_2_lines) {
    y += PROGRAM_LABEL_2L_SPACING;
    tft.setCursor(centerXForText(labels[1]), y);
    tft.print(labels[1]);
  }

  tft.setTextWrap(false);
}

void _drawBarOutlines() {
  for (int i = 0; i < 3; i++) {
    tft.drawRect(0, BAR_Y_START + i * BAR_SECTION_TOTAL_HEIGHT + BAR_TEXT_MAX_HEIGHT, BAR_WIDTH + 2 * BAR_MARGIN, BAR_HEIGHT + 2 * BAR_MARGIN, BAR_OUTLINE_COLOR);
  }
}

/* Fills in all the bars. Call frequently. */
int last_pot_val[] = {0, 0, 0, 0, 0};
void drawBars(boolean force = false) {
  for (int i = 0; i < 3; i++) {
    int pot_val = analogRead(pot_pins[i]);

    if (!force && abs(pot_val - last_pot_val[i]) <= BAR_SMOOTHING) {
      /* Don't redraw if it hasn't moved much.
         This prevents the bar from flickering, as well as
         stuttering back and forth.
      */
      continue;
    } else {
      last_pot_val[i] = pot_val;
    }

    float percent = ((float)pot_val / 1023);
    if (percent > 1) {
      percent = 1;
    }

    int width = percent * BAR_WIDTH;
    int y = BAR_Y_START + i * BAR_SECTION_TOTAL_HEIGHT + BAR_TEXT_MAX_HEIGHT + BAR_MARGIN;
    tft.fillRect(BAR_MARGIN, y, width, BAR_HEIGHT, bar_colors[i][0]);
    tft.fillRect(BAR_MARGIN + width, y, BAR_WIDTH - width, BAR_HEIGHT, bar_colors[i][1]);
  }
}

/* Get X position for text if we want to center it. */
int centerXForText(char *text) {
  int16_t  x, y;
  uint16_t w, h;
  // getTextBounds() seems to have a bug. Some text ("Modulated Reverb") results in a width that's too large.
  tft.getTextBounds(text, 50, 1, &x, &y, &w, &h);
  return (w < TFT_WIDTH ? ((TFT_WIDTH - w) / 2) : 0);
}

/* This pulls labels off of EEPROM based on selected_bank and selected_program. */
void _setLabelsForSelectedProgram() {
  //Serial.println("Setting labels");
  //Serial.print("selected_bank="); Serial.println(selected_bank);
  //Serial.print("internal="); Serial.println(BANK_INTERNAL);
  //Serial.print("error="); Serial.println(BANK_ERROR);

  if (selected_bank == BANK_INTERNAL || selected_bank == BANK_ERROR) {
    _setLabelsForROM();
  } else {
    _setLabelsForExternalEEPROM();
  }
}

void _setLabelsForExternalEEPROM() {
  //Serial.println("Setting labels for EEPROM");
  // 5 == 5 strings per program
  /* (starting position for bank) + (starting position for program) */
  unsigned int base_address = (EEPROM_PAGE_SIZE * 5 * selected_program);
  for (int i = 0; i < 5; i++) {
    unsigned int address = base_address + EEPROM_PAGE_SIZE * i;
    Wire.beginTransmission(EEPROM_ADDRESS);
    Wire.write((int)(address >> 8)); // MSB
    Wire.write((int)(address & 0xFF)); // LSB
    Wire.endTransmission();

    Wire.requestFrom(EEPROM_ADDRESS, EEPROM_BUFFER_SIZE);
    byte data = '\0';
    for (int j = 0; j < EEPROM_BUFFER_SIZE; j++) {
      if (Wire.available()) {
        data = Wire.read();
        labels[i][j] = data;
        //Serial.write(data);
        if (data == '\0') {
          break;
        }
      }
    }
    //Serial.println("");
  }
}

void _setLabelsForROM() {
  //Serial.println("Setting labels for internal rom");
  switch (selected_program) {
    case 0:
      strcpy(labels[0], "Chorus Reverb\0");
      strcpy(labels[1], "\0");
      strcpy(labels[2], "Reverb Mix\0");
      strcpy(labels[3], "Chorus Rate\0");
      strcpy(labels[4], "Chorus Mix\0");
      break;
    case 1:
      strcpy(labels[0], "Flange Reverb\0");
      strcpy(labels[1], "\0");
      strcpy(labels[2], "Reverb Mix\0");
      strcpy(labels[3], "Flange Rate\0");
      strcpy(labels[4], "Flange Mix\0");
      break;
    case 2:
      strcpy(labels[0], "Tremolo Reverb\0");
      strcpy(labels[1], "\0");
      strcpy(labels[2], "Reverb Mix\0");
      strcpy(labels[3], "Tremolo Rate\0");
      strcpy(labels[4], "Tremolo Mix\0");
      break;
    case 3:
      strcpy(labels[0], "Pitch Shift\0");
      strcpy(labels[1], "\0");
      strcpy(labels[2], "Pitch +/- 4 semitones\0");
      strcpy(labels[3], "N/A\0");
      strcpy(labels[4], "N/A\0");
      break;
    case 4:
      strcpy(labels[0], "Pitch Echo\0");
      strcpy(labels[1], "\0");
      strcpy(labels[2], "Pitch Shift\0");
      strcpy(labels[3], "Echo Delay\0");
      strcpy(labels[4], "Echo Mix\0");
      break;
    case 5:
      strcpy(labels[0], "Unavailable\0");
      strcpy(labels[1], "\0");
      strcpy(labels[2], "-\0");
      strcpy(labels[3], "-\0");
      strcpy(labels[4], "-\0");
      break;
    case 6:
      strcpy(labels[0], "Room Reverb 1\0");
      strcpy(labels[1], "\0");
      strcpy(labels[2], "Time\0");
      strcpy(labels[3], "HF Filter\0");
      strcpy(labels[4], "LF Filter\0");
      break;
    case 7:
      strcpy(labels[0], "Room Reverb 2\0");
      strcpy(labels[1], "\0");
      strcpy(labels[2], "Time\0");
      strcpy(labels[3], "HF Filter\0");
      strcpy(labels[4], "LF Filter\0");
      break;
  }
}

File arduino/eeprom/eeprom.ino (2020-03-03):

#include <Wire.h>

/* We're using a 24LC32A */
// Make sure all of these match what's in the pedal's code, too.
#define EEPROM_ADDRESS B1010000 // 1010 + 3 bits for pins 1,2,3
#define BUFFER_SIZE 30 // It has a 32 byte page write buffer, but we use as little as possible to save space on the arduino's RAM.
#define PAGE_SIZE 32
#define EEPROM_CLOCK_SPEED 400000


/* This is interpretted as sets of 5 strings: the program name, optional line 2 of program name, then 3 control labels.
*/
#define NUM_STRINGS 5  // 5 strings per program
#define NUM_PROGRAMS 8 // 8 programs per bank
#define NUM_BANKS 1   // one bank per eeprom. V1 of the pedal also stored the internal ROM bank on here.
char *labels[] = {
  "Room Reverb\0",
  "\0",
  "Dwell\0",
  "Pre-Delay\0",
  "Dampen\0",

  "Hall Reverb\0",
  "\0",
  "Dwell\0",
  "Pre-Delay\0",
  "Dampen\0",

  "Chamber Reverb\0",
  "\0",
  "Dwell\0",
  "Low\0",
  "High\0",

  "Cavern Reverb\0",
  "\0",
  "Dwell\0",
  "Low\0",
  "High\0",

  "Shimmer Reverb\0",
  "\0",
  "Dwell\0",
  "Shimmer Pitch\0",
  "Shimmer Level\0",

  "Modulated Reverb\0",
  "\0",
  "Dwell\0",
  "Mod Depth\0",
  "Mod Rate\0",

  "Pitch Verb\0",
  "\0",
  "Dwell\0",
  "Octave Down\0",
  "Octave Up\0",

  "Touch Reverb\0",
  "\0",
  "Dwell\0",
  "Ducking\0",
  "Sensitivity\0"
};



void setup() {
  Serial.begin(9600);

  Wire.begin();
  Wire.setClock(EEPROM_CLOCK_SPEED);

  unsigned int address = 0x0;
  for (int i = 0; i < NUM_STRINGS * NUM_PROGRAMS * NUM_BANKS; i++) {
    Serial.print(address);
    Serial.print(": ");
    Serial.println(labels[i]);
    writeEEPROMPage(address, labels[i]);
    address = address + PAGE_SIZE;
  }

  Serial.println("***********DONE************");
}

void loop() {
}

/* NOTE: This is not general purpose. It's only useful for writing within a single page.
    Address needs to be the start of a page.
*/
void writeEEPROMPage(unsigned int address, char *data)
{
  unsigned char i = 0;

  Wire.beginTransmission(EEPROM_ADDRESS);

  Wire.write((int)(address >> 8)); // most significant byte
  Wire.write((int)(address & 0xFF)); // least significant byte

  while (i < BUFFER_SIZE) {
    // Serial.println(i);
    // Serial.println(data[i]);
    Wire.write((byte) data[i]);
    if (data[i] == '\0') {
      break;
    }
    i++;
  }

  //Serial.println("Ending transmission");
  Wire.endTransmission();
  //Serial.println("Ended");
  delay(6);  // needs 5ms for page write
}

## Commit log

2020-03-03 Rearranged into v1 and v2 dirs.
    [eeprom prgramming.fzz, mimirs-well-2.3.dxf]
2020-03-12 added BOM, Layout
    [mimirs-well-2.3.dxf]
2020-03-27 mv v2/* ./
    [mimirs-well-2.3.dxf]
2020-04-12 added updated schematic
2020-04-20 WIP on new site (to change soon though....)
    I'm going to get rid of the "mode" selection.
    Committing to preserve this, just in case
    I want it back later
2020-05-29 added drill templates
2020-05-29 consolidated drill templates
2020-06-21 added scripts for burning label EEPROMs without an arduino
2020-07-19 updated gerber files
    [mimirs-well-2.3.dxf, mimirs-well-2.4.dxf]
2022-09-25 updated drill template
2022-11-23 added v2.5 PCBs
    [mimirs-well-2.5.dxf]
2023-02-11 added wiring guide
2023-02-11 added missing wire to wiring guide
2023-03-27 add qty to BOM
